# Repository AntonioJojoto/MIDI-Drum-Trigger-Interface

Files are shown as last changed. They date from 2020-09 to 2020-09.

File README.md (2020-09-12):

# Low-Cost MIDI Drum Trigger Interface

Many people may not know this, but drums are expensive, and if you live in an apartment, you can't just buy a cheap acoustic set and play, as your neighbors will call the police before you can finish playing your first song because an acoustic set can easily reach +110 dB.

However, there is another option, electronic drums. They are so silent that your roommates won't even complain (if you play at 3AM they might). But there is one **big** drawback to edrums, they are **too expensive**.

A low-tier edrum can go around 400€, I currently own a Yamaha DTX450k and I got a deal for it at 440€, as it normally goes for 550€ and when I was staring to practice it was OK, but then I got the chance to practice for a year on a acoustic set, and when I had to return to my cheap set I started to notice the drawback of cheap electronic drumsets. 

Here are some problems that you may encounter when you play a cheap electronic set:
- The sounds from the module are awful, specially the cymbals.
- The pads are tiny and hard, in my Yamaha Drumset, they are 8 inches wide.
- All the pads and cymbals are single-zone, so no rimshot, bell sound or anything else.
- Hihat pedal is only in open or closed position, you can't get a lot of sounds from it.
- In my case, as I like to play hard, the drum rack was moving a lot. The snare is always falling.

Sure, all of these problems may disappear as you upgrade to a more expensive drum set, but you will have to spend around 1200€. But even then, it will still be a mid-tier electronic drumset.

The best option, in my opinion, is to convert an acoustic set into an electronic one. If you already have an acoustic set or if you don't have one, as you can get one for 100€ or 200€. Now, there are two options for electronic conversion, buy the triggers and cymbals or go the DIY route, which is **much cheaper**. Although there is one expensive component that all the DIY guides asks for, the **Drum Module**.

It is normally the most expensive component in every drumset. The job of this component is critical, read the signals from the triggers and make a sound accordingly. Drum modules can go for around 300€ to 700€, but instead of buying a module that produce a mediocre sound, you should buy or make a trigger interface, is the same a drum module but instead of producing the sounds by itself, it sends MIDI notes to your computer, which will always produce better sound than even the most expensive modules.

Trigger Interfaces are much cheaper, the DDrum Trigger Interface will work perfectly for only 170€, but you can even make this component yourself.

**DISCLAIMER**: From now on, the guide will center on build the interface, in the following months a guide on DIY trigger and cymbals will be available. But from now, there is plenty of information online.

# Current Features
- 16 single-zone channels.
- Custom values for each channel (scan time,dead time,etc).
- MIDI-over-USB Interface.
- Less than 3 milliseconds latency.

# Future Features
- [x] Schematic. 
- [x] Cross-Talk.
- [ ] Support for custom dual and triple zone cymbals.
- [ ] Support for rimshot on snare. 
- [ ] Hihat Pedal using optical sensor.
- [ ] Change values using LCD screen and keypad.
- [ ] Save custom values in EEPROM.
- [ ] PCB available for production.

# How it works?

There are many Arduino drum modules online, but a common problem in all of them is the latency, I find that an Arduino isn't fast enough to process the raw piezo signal from several channels, which is the approach that many people follow when making the interface. 

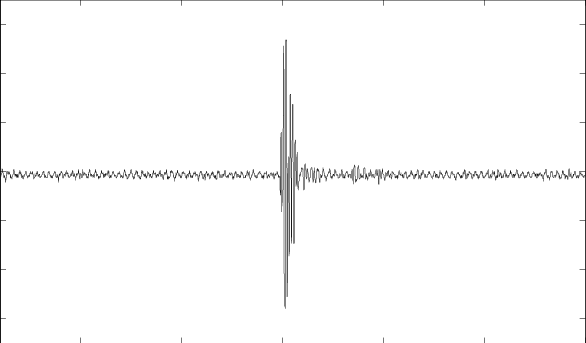
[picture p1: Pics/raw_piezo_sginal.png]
Raw Piezo Signal


As seen in the picture, the peak of a piezo may only occur in the span of 100us. So the microcontroller may not read the channel at just the peak, so it will send no MIDI value at all, or send a wrong value. That is why in my desing I decided to add a **peak detector circuit** per channel.

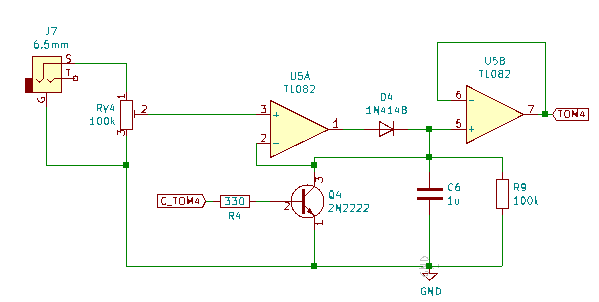
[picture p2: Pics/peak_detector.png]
Peak Detector Circuit


This circuit maintains the highest voltage from the piezo, so the voltage of the peak will be available for the uC to be read. Once the peak value has been registered, the capacitor will be discharged through the transistor, reseting the peak detector.

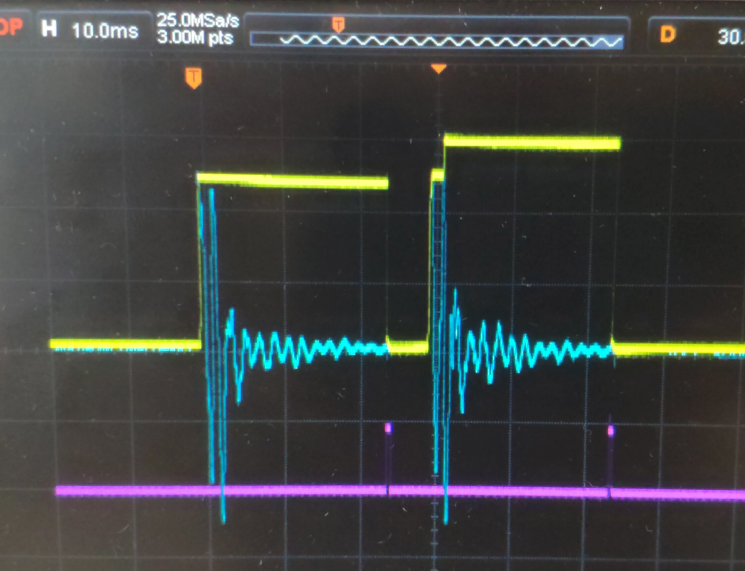
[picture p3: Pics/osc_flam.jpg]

- **Yellow Signal**: Raw piezo signal.
- **Blue Signal**: Peak detector output.
- **Pink Signal**: Transistor gate.

Once the uC detects a value on the channels higher than a given **threshold**, it wait a couple of milliseconds for the signal to reach the peak, this period is called **scan time**, after that, the value of the channel is read. But to stop retriggering, the uC won't clear the detector once a **dead time** has finished. All of these values are standarts from drum modules, and they can be set from channel to channel. 

Using this method, we ensure that only the peak value of the piezo will be read, also no hits will be lost because the uC can read each channel at its own pace. In this example, the hit was a flam, and it registered both hits, although they were 30 milliseconds apart.

# List of materials.

This desing is centered arround the AtMega 2560, as I want more than 6 channels for a full electronic set. But an AtMega328p can also be used, it depends on the number of channels that you want to use.

### Material per module.
- AtMega 2560 or AtMega328p. Although I recommend an Arduino, as the AtMega16 will be used to send the MIDI events over USB.
- ISP Programmer: USBTiny or another Arduino.
- LM7660 positive to negative voltage converter. 

### Materials per channel.

- Female Jack (3.5mm or 6.5mm).
- Male Jack (3.5mm or 6.5mm).
- 2N2222 NPN BJT.
- 10k and 330 resistors.
- 1uF ceramic capacitor.
- 1N4148 Diode.
- TL082 Operational Amplifier.

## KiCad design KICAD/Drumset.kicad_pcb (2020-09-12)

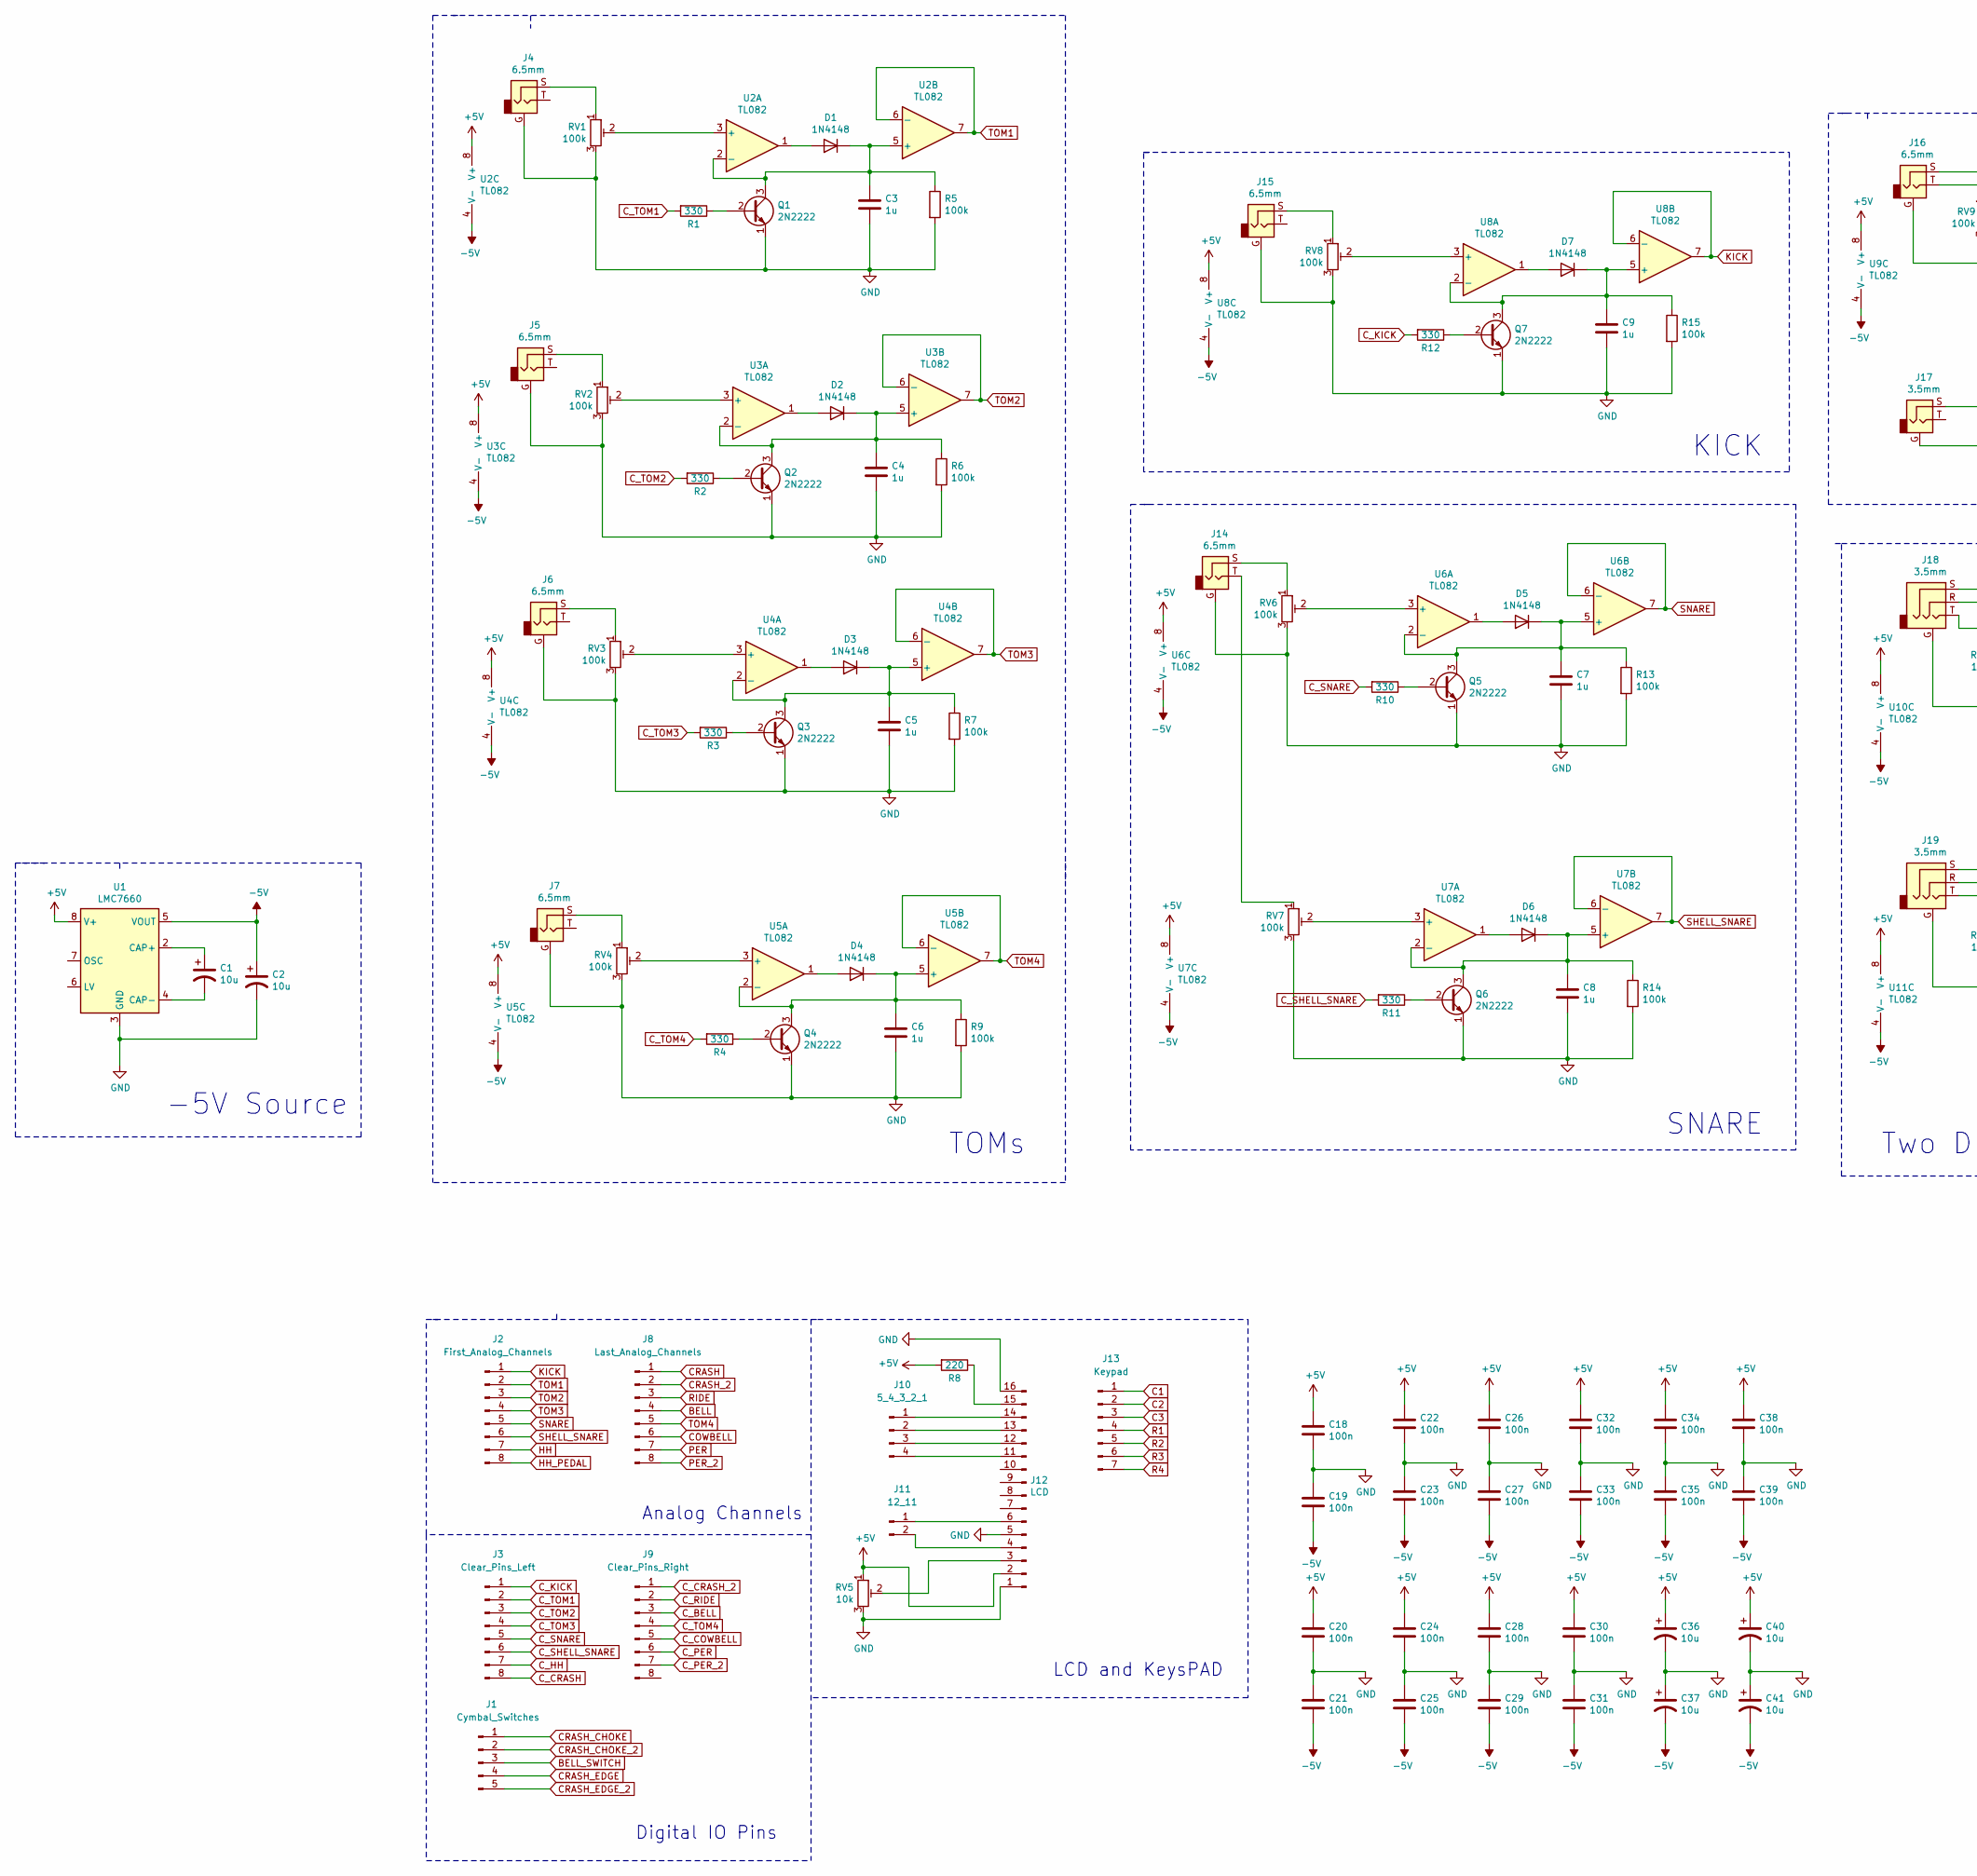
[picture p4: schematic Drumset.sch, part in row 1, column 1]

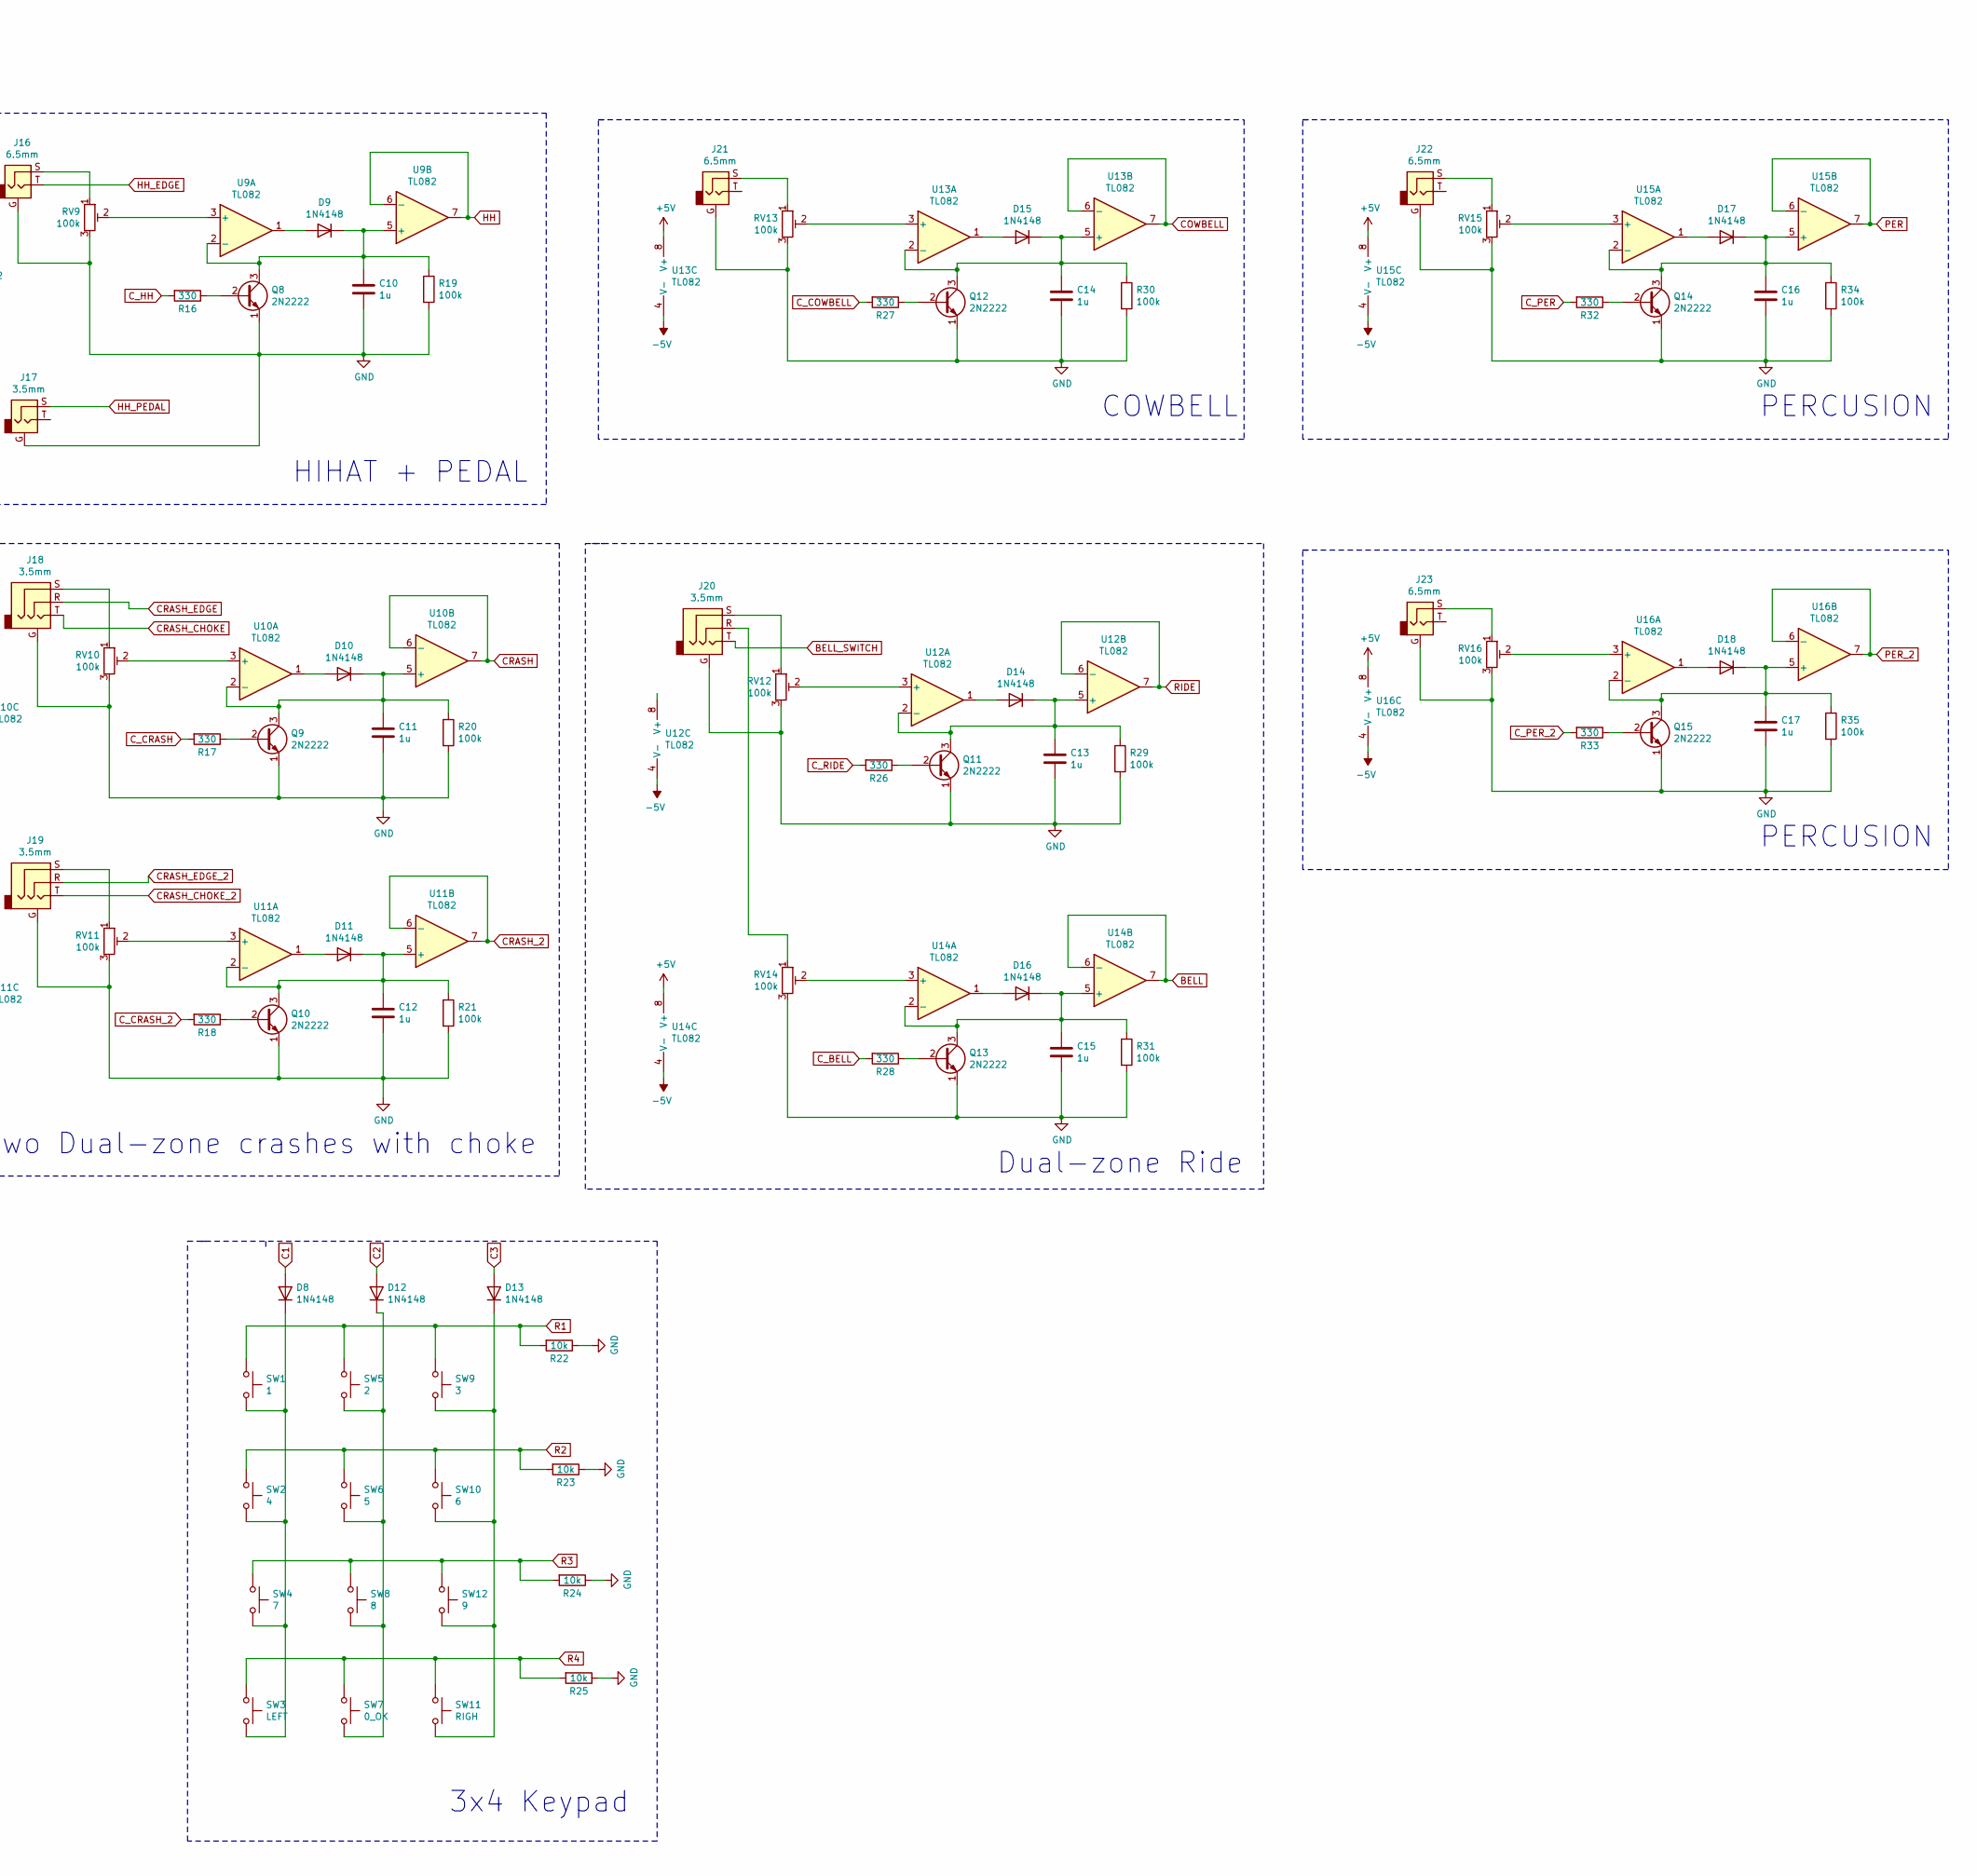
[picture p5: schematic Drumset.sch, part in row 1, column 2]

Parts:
C1, C2, C40, C41: 10u; CP_Radial_D6.3mm_P2.50mm
C3, C4, C5, C6, C7, C8, C9, C10, C11, C12, C13, C14, C15, C16, C17: 1u; C_Disc_D8.0mm_W5.0mm_P5.00mm
C18, C19, C20, C21, C22, C23, C24, C25, C26, C27, C28, C29, C30, C31, C32, C33, C34, C35, C38, C39: 100n; C_Disc_D3.8mm_W2.6mm_P2.50mm
C36, C37: 10u; C_Disc_D3.8mm_W2.6mm_P2.50mm
D1, D2, D3, D4, D5, D6, D7, D8, D9, D10, D11, D12, D13, D14, D15, D16, D17, D18: 1N4148; D_DO-35_SOD27_P10.16mm_Horizontal
J1: Cymbal_Switches; PinHeader_1x05_P2.54mm_Vertical
J2: First_Analog_Channels; PinHeader_1x08_P2.54mm_Vertical
J3: Clear_Pins_Left; PinHeader_1x08_P2.54mm_Vertical
J4, J5, J6, J7, J14, J15, J16, J21, J22, J23: 6.5mm; Jack_6.35mm_Neutrik_NRJ6HM-1-AU_Horizontal
J8: Last_Analog_Channels; PinHeader_1x08_P2.54mm_Vertical
J9: Clear_Pins_Right; PinHeader_1x08_P2.54mm_Vertical
J10: 5_4_3_2_1; PinHeader_1x05_P2.54mm_Vertical
J11: 12_11; PinHeader_1x02_P2.54mm_Vertical
J12: LCD; PinHeader_1x16_P2.54mm_Vertical
J13: Keypad; PinHeader_1x07_P2.54mm_Vertical
J17, J18, J19, J20: 3.5mm; Jack_3.5mm_PJ320D_Horizontal
Q1, Q2, Q3, Q4, Q5, Q6, Q7, Q8, Q9, Q10, Q11, Q12, Q13, Q14, Q15: 2N2222; TO-92_Inline_Wide
R1, R2, R3, R4, R10, R11, R12, R16, R17, R18, R26, R27, R28, R32, R33: 330; R_Axial_DIN0207_L6.3mm_D2.5mm_P10.16mm_Horizontal
R5, R6, R7, R9, R13, R14, R15, R19, R20, R21, R29, R30, R31, R34, R35: 100k; R_Axial_DIN0207_L6.3mm_D2.5mm_P10.16mm_Horizontal
R8: 220; R_Axial_DIN0207_L6.3mm_D2.5mm_P10.16mm_Horizontal
R22, R23, R24, R25: 10k; R_Axial_DIN0207_L6.3mm_D2.5mm_P10.16mm_Horizontal
RV1, RV2, RV3, RV4, RV6, RV7, RV8, RV9, RV10, RV11, RV12, RV13, RV14, RV15, RV16: 100k; Potentiometer_Bourns_3266Y_Vertical
RV5: 10k; Potentiometer_Piher_PT-10-V05_Vertical
SW1: 1; SW_PUSH_6mm_H4.3mm
SW2: 4; SW_PUSH_6mm_H4.3mm
SW3: LEFT; SW_PUSH_6mm_H4.3mm
SW4: 7; SW_PUSH_6mm_H4.3mm
SW5: 2; SW_PUSH_6mm_H4.3mm
SW6: 5; SW_PUSH_6mm_H4.3mm
SW7: 0_OK; SW_PUSH_6mm_H4.3mm
SW8: 8; SW_PUSH_6mm_H4.3mm
SW9: 3; SW_PUSH_6mm_H4.3mm
SW10: 6; SW_PUSH_6mm_H4.3mm
SW11: RIGH; SW_PUSH_6mm_H4.3mm
SW12: 9; SW_PUSH_6mm_H4.3mm
U1: LMC7660; DIP-8_W7.62mm_Socket
U2, U3, U4, U5, U6, U7, U8, U9, U10, U11, U12, U13, U14, U15, U16: TL082; DIP-8_W7.62mm_Socket

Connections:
+5V: C18.1, C20.1, C22.1, C24.1, C26.1, C28.1, C30.1, C32.1, C34.1, C36.1, C38.1, C40.1, J12.2, R8.2, RV5.1, U1.8 (V+), U2.8 (V+), U3.8 (V+), U4.8 (V+), U5.8 (V+), U6.8 (V+), U7.8 (V+), U8.8 (V+), U9.8 (V+), U10.8 (V+), U11.8 (V+), U13.8 (V+), U14.8 (V+), U15.8 (V+), U16.8 (V+)
-5V: C2.1, C19.2, C21.2, C23.2, C25.2, C27.2, C29.2, C31.2, C33.2, C35.2, C37.2, C39.2, C41.2, U1.5 (VOUT), U2.4 (V-), U3.4 (V-), U4.4 (V-), U5.4 (V-), U6.4 (V-), U7.4 (V-), U8.4 (V-), U9.4 (V-), U10.4 (V-), U11.4 (V-), U12.4 (V-), U13.4 (V-), U14.4 (V-), U15.4 (V-), U16.4 (V-)
BELL: J8.4, U14.6 (-), U14.7
BELL_SWITCH: J1.3, J20.T
C1: D8.2 (A), J13.1
C2: D12.2 (A), J13.2
C3: D13.2 (A), J13.3
COWBELL: J8.6, U13.6 (-), U13.7
CRASH: J8.1, U10.6 (-), U10.7
CRASH_2: J8.2, U11.6 (-), U11.7
CRASH_CHOKE: J1.1, J18.T
CRASH_CHOKE_2: J1.2, J19.T
CRASH_EDGE: J1.4, J18.R
CRASH_EDGE_2: J1.5, J19.R
C_BELL: J9.3, R28.2
C_COWBELL: J9.5, R27.2
C_CRASH: J3.8, R17.2
C_CRASH_2: J9.1, R18.2
C_HH: J3.7, R16.2
C_KICK: J3.1, R12.2
C_PER: J9.6, R32.2
C_PER_2: J9.7, R33.2
C_RIDE: J9.2, R26.2
C_SHELL_SNARE: J3.6, R11.2
C_SNARE: J3.5, R10.2
C_TOM1: J3.2, R1.2
C_TOM2: J3.3, R2.2
C_TOM3: J3.4, R3.2
C_TOM4: J9.4, R4.2
GND: C2.2, C3.2, C4.2, C5.2, C6.2, C7.2, C8.2, C9.2, C10.2, C11.2, C12.2, C13.2, C14.2, C15.2, C16.2, C17.2, C18.2, C19.1, C20.2, C21.1, C22.2, C23.1, C24.2, C25.1, C26.2, C27.1, C28.2, C29.1, C30.2, C31.1, C32.2, C33.1, C34.2, C35.1, C36.2, C37.1, C38.2, C39.1, C40.2, C41.1, J4.G, J5.G, J6.G, J7.G, J12.1, J12.5, J12.16, J14.G, J15.G, J16.G, J17.G, J18.G, J19.G, J20.G, J21.G, J22.G, J23.G, Q1.1 (E), Q2.1 (E), Q3.1 (E), Q4.1 (E), Q5.1 (E), Q6.1 (E), Q7.1 (E), Q8.1 (E), Q9.1 (E), Q10.1 (E), Q11.1 (E), Q12.1 (E), Q13.1 (E), Q14.1 (E), Q15.1 (E), R5.2, R6.2, R7.2, R9.2, R13.2, R14.2, R15.2, R19.2, R20.2, R21.2, R22.1, R23.1, R24.1, R25.1, R29.2, R30.2, R31.2, R34.2, R35.2, RV1.3, RV2.3, RV3.3, RV4.3, RV5.3, RV6.3, RV7.3, RV8.3, RV9.3, RV10.3, RV11.3, RV12.3, RV13.3, RV14.3, RV15.3, RV16.3, U1.3 (GND)
HH: J2.7, U9.6 (-), U9.7
HH_EDGE: J16.T
HH_PEDAL: J2.8, J17.S
KICK: J2.1, U8.6 (-), U8.7
unnamed: C1.1, U1.2 (CAP+)
unnamed: C1.2, U1.4 (CAP-)
unnamed: C3.1, D1.1 (K), Q1.3 (C), R5.1, U2.2 (-), U2.5 (+)
unnamed: C4.1, D2.1 (K), Q2.3 (C), R6.1, U3.2 (-), U3.5 (+)
unnamed: C5.1, D3.1 (K), Q3.3 (C), R7.1, U4.2 (-), U4.5 (+)
unnamed: C6.1, D4.1 (K), Q4.3 (C), R9.1, U5.2 (-), U5.5 (+)
unnamed: C7.1, D5.1 (K), Q5.3 (C), R13.1, U6.2 (-), U6.5 (+)
unnamed: C8.1, D6.1 (K), Q6.3 (C), R14.1, U7.2 (-), U7.5 (+)
unnamed: C9.1, D7.1 (K), Q7.3 (C), R15.1, U8.2 (-), U8.5 (+)
unnamed: C10.1, D9.1 (K), Q8.3 (C), R19.1, U9.2 (-), U9.5 (+)
unnamed: C11.1, D10.1 (K), Q9.3 (C), R20.1, U10.2 (-), U10.5 (+)
unnamed: C12.1, D11.1 (K), Q10.3 (C), R21.1, U11.2 (-), U11.5 (+)
unnamed: C13.1, D14.1 (K), Q11.3 (C), R29.1, U12.2 (-), U12.5 (+)
unnamed: C14.1, D15.1 (K), Q12.3 (C), R30.1, U13.2 (-), U13.5 (+)
unnamed: C15.1, D16.1 (K), Q13.3 (C), R31.1, U14.2 (-), U14.5 (+)
unnamed: C16.1, D17.1 (K), Q14.3 (C), R34.1, U15.2 (-), U15.5 (+)
unnamed: C17.1, D18.1 (K), Q15.3 (C), R35.1, U16.2 (-), U16.5 (+)
unnamed: D1.2 (A), U2.1
unnamed: D2.2 (A), U3.1
unnamed: D3.2 (A), U4.1
unnamed: D4.2 (A), U5.1
unnamed: D5.2 (A), U6.1
unnamed: D6.2 (A), U7.1
unnamed: D7.2 (A), U8.1
unnamed: D8.1 (K), SW1.2, SW2.2, SW3.2, SW4.2
unnamed: D9.2 (A), U9.1
unnamed: D10.2 (A), U10.1
unnamed: D11.2 (A), U11.1
unnamed: D12.1 (K), SW5.2, SW6.2, SW7.2, SW8.2
unnamed: D13.1 (K), SW9.2, SW10.2, SW11.2, SW12.2
unnamed: D14.2 (A), U12.1
unnamed: D15.2 (A), U13.1
unnamed: D16.2 (A), U14.1
unnamed: D17.2 (A), U15.1
unnamed: D18.2 (A), U16.1
unnamed: J4.S, RV1.1
unnamed: J5.S, RV2.1
unnamed: J6.S, RV3.1
unnamed: J7.S, RV4.1
unnamed: J10.1, J12.14
unnamed: J10.2, J12.13
unnamed: J10.3, J12.12
unnamed: J10.4, J12.11
unnamed: J11.1, J12.6
unnamed: J11.2, J12.4
unnamed: J12.3, RV5.2
unnamed: J12.15, R8.1
unnamed: J14.S, RV6.1
unnamed: J14.T, RV7.1
unnamed: J15.S, RV8.1
unnamed: J16.S, RV9.1
unnamed: J18.S, RV10.1
unnamed: J19.S, RV11.1
unnamed: J20.R, RV14.1
unnamed: J20.S, RV12.1
unnamed: J21.S, RV13.1
unnamed: J22.S, RV15.1
unnamed: J23.S, RV16.1
unnamed: Q1.2 (B), R1.1
unnamed: Q2.2 (B), R2.1
unnamed: Q3.2 (B), R3.1
unnamed: Q4.2 (B), R4.1
unnamed: Q5.2 (B), R10.1
unnamed: Q6.2 (B), R11.1
unnamed: Q7.2 (B), R12.1
unnamed: Q8.2 (B), R16.1
unnamed: Q9.2 (B), R17.1
unnamed: Q10.2 (B), R18.1
unnamed: Q11.2 (B), R26.1
unnamed: Q12.2 (B), R27.1
unnamed: Q13.2 (B), R28.1
unnamed: Q14.2 (B), R32.1
unnamed: Q15.2 (B), R33.1
unnamed: RV1.2, U2.3 (+)
unnamed: RV2.2, U3.3 (+)
unnamed: RV3.2, U4.3 (+)
unnamed: RV4.2, U5.3 (+)
unnamed: RV6.2, U6.3 (+)
unnamed: RV7.2, U7.3 (+)
unnamed: RV8.2, U8.3 (+)
unnamed: RV9.2, U9.3 (+)
unnamed: RV10.2, U10.3 (+)
unnamed: RV11.2, U11.3 (+)
unnamed: RV12.2, U12.3 (+)
unnamed: RV13.2, U13.3 (+)
unnamed: RV14.2, U14.3 (+)
unnamed: RV15.2, U15.3 (+)
unnamed: RV16.2, U16.3 (+)
PER: J8.7, U15.6 (-), U15.7
PER_2: J8.8, U16.6 (-), U16.7
R1: J13.4, R22.2, SW1.1, SW5.1, SW9.1
R2: J13.5, R23.2, SW2.1, SW6.1, SW10.1
R3: J13.6, R24.2, SW4.1, SW8.1, SW12.1
R4: J13.7, R25.2, SW3.1, SW7.1, SW11.1
RIDE: J8.3, U12.6 (-), U12.7
SHELL_SNARE: J2.6, U7.6 (-), U7.7
SNARE: J2.5, U6.6 (-), U6.7
TOM1: J2.2, U2.6 (-), U2.7
TOM2: J2.3, U3.6 (-), U3.7
TOM3: J2.4, U4.6 (-), U4.7
TOM4: J8.5, U5.6 (-), U5.7

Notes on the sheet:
KICK
SNARE
-5V Source
HIHAT + PEDAL
Two Dual-zone crashes with choke
Dual-zone Ride
TOMs
COWBELL
PERCUSION
Analog Channels
3x4 Keypad
Digital IO Pins
LCD and KeysPAD

Board: 2 copper layers, 176 parts (0 on the bottom side), 134 nets, no tracks yet.

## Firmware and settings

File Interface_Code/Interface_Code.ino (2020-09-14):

#include <MIDI.h>

MIDI_CREATE_DEFAULT_INSTANCE();

#define max_channels 3

// The variables where piezo values will be stored
int buff;
// Notes on the state variable:
// 0 -> No trigger
// 1 -> Threshold reach, wait for scan time
// 2 -> Waiting for dead time, midi note send. 
int state[max_channels];
int value[max_channels];
int vel[max_channels];
unsigned long t[max_channels];
// Snare, kick, closed hihat
const byte note[max_channels]={36,38,1};
// Pin to clear the peak detector 
const byte circuit[max_channels]={12,11,10};

// Future releases will have this stored in the EEPROM

// Threshold aumentado
int threshold[max_channels]={40,40,40};
int max_value[max_channels]={600,400,600};
float scan_time[max_channels]={3,3,3};
float dead_time[max_channels]={30,40,30};

// Time transistor is active
int clear_delay[max_channels]={1000,1000,1000};
byte curve[max_channels]={1,1,1};


void setup()
{
	// Initialize MIDI
	MIDI.begin(MIDI_CHANNEL_OMNI);
	// Set digital Pins as output
	// Set all states to zero
	for(int a=0;a<=max_channels;a++){
		state[a]=0;
		pinMode(circuit[a],OUTPUT);
	}
}

void loop()
{
	for(int channel=0;channel<=max_channels;channel++){
	
	// If not in dead time wait, read the channel 
	if(state[channel]!=2){
		// Read the input 
		buff=analogRead(channel);
		// Threshold is reached? Start counting scan time 
		if((buff>=threshold[channel])&&(state[channel]==0)){
			state[channel]=1;
			t[channel]=micros();
		}
		
		// This reading is OK, so save it to be sent over midi 
		if((state[channel]==1)&&((micros()-t[channel])>=(scan_time[channel]*1000))){
			
			// The map function should be sustituted with the velovity curve
			vel[channel]=map(buff,threshold[channel],max_value[channel],2,127);
			
			// 7-bit MIDI note, so between 1 and 127
			if(vel[channel]>127){vel[channel]=127;}
			MIDI.sendNoteOn(note[channel],vel[channel],1);
			// Set next state for dead time counting
			state[channel]=2;
			t[channel]=micros();
			}
	}
	// Counting deadtime
	else{
		// Dead time is over 
		if((micros()-t[channel])>=(dead_time[channel]*1000)){

			// Clear peak detector
			digitalWrite(circuit[channel],HIGH);
			delayMicroseconds(clear_delay[channel]);
			digitalWrite(circuit[channel],LOW);
			delayMicroseconds(clear_delay[channel]);
			// Ready to receive again
			state[channel]=0;

	}
	}
}


}

// Periodo para leer los 6 canales son unos 800us






	

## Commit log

2020-09-12 Adding the kicad files
    [Drumset.kicad_pcb, Drumset.sch]
2020-09-14 Stable, 3 channels for prototype
2020-09-22 Fixed the 32 midi note error, check out 2 commits before
    [Interface_Code.ino]
